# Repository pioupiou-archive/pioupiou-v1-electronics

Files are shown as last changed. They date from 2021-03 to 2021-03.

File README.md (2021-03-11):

# pioupiou-v1-electronics

This repository contains the electronic parts of the Pioupiou V1 wind sensor.

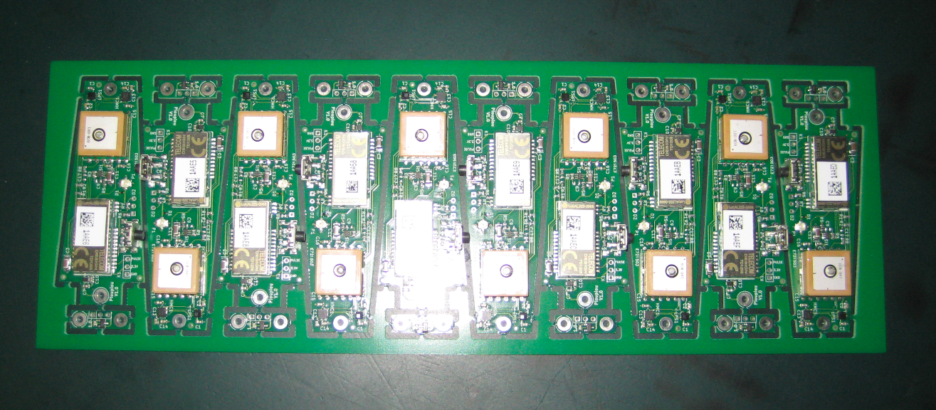
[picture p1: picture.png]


## DEPRECATION NOTICE
**THIS REPOSITORY IS NO LONGER ACTIVE.**

**PLEASE MOVE TO THE NEW PROJECT: https://github.com/windbird-sensor/windbird-electronics**

## License

Copyright (c) 2015 Bac Plus Zéro SAS

Copyright (c) 2016 Altostratus SA

Copyright (c) 2021 OpenWindMap SCIC SA and contributors

**Permission is granted to anyone to use this Material for any purpose, including commercial applications, and to alter it and redistribute it freely, subject to the following restrictions:**

**ATTRIBUTION:** You must give appropriate credit, provide a link to the license, and indicate if changes were made. You may do so in any reasonable manner, but not in any way that suggests the licensor endorses you or your use.

**SHARE-ALIKE:** If you remix, transform, or build upon the Material, you must distribute your contributions under the same license as the original. You must include a copy of this License with every copy of this Material or modified version of this Material You distribute or otherwise make available.

**OBLIGATION TO SHARE WITHIN THE OPENWINDMAP NETWORK:** If you use this Material or a modified version of this Material to build a product that collects environmental data, this data must be published within the OpenWindMap network. You must not intentionally degrade the quality of the data, reduce the accuracy of its geolocation or delay its dissemination.

**OPEN-DATA:** If you use this Material or a modified version of this Material to build a product that collects environmental data, this data should be published under an Open-Data license. The chosen license must allow free reuse and redistribution, including from commercial entities and for commercial use. The choosen license must either be compliant with the [Open Definition](https://opendefinition.org/od/2.1/en/) or receive approval from OpenWindMap's board. You are allowed to offer a version of this data under any other license of your choice (including non-free licenses), as long as you also provide an identical version of this data under an Open-Data license as defined in this paragraph.

**DISCLAIMER OF WARRANTY/LIMITATION OF REMEDIES:** OpenWindMap and its contributors have no obligation to support this Material. OpenWindMap and its contributors are providing this Material "AS IS", with no express or implied warranties of any kind, including, but not limited to, any implied warranties of merchantability or fitness for any particular purpose or warranties against infringement of any proprietary rights of a third party.

**OpenWindMap and its contributors will not be liable for any consequential, incidental, or special damages, or any other relief, or for any claim by any third party, arising from your use of this Material.**

For the avoidance of doubt, OpenWindMap may offer this Material under separate terms or conditions or stop distributing this Material at any time; however, doing so will not terminate this License.

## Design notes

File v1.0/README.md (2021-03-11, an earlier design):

Attention : incohérence de numérotation des composants entre le schéma PDF et les autres fichiers

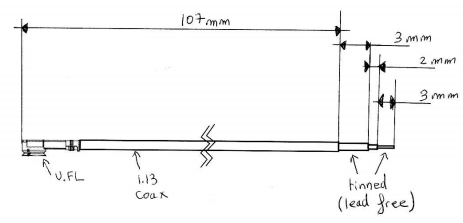
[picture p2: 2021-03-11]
v1.1/antenna coax cable.jpg

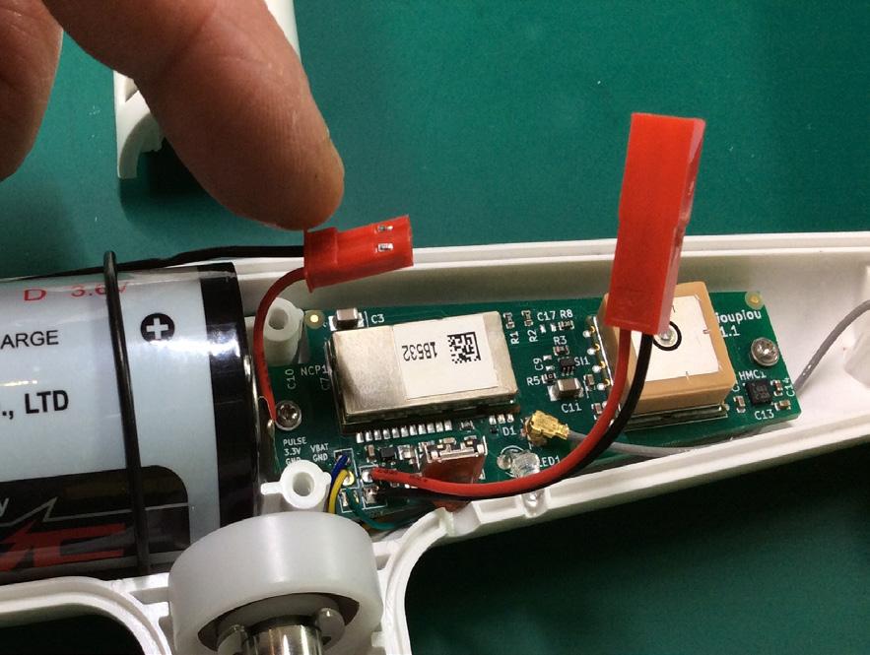
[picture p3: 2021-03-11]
v1.1/battery connector polarity.jpg

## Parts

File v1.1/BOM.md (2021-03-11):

| **Designator** | **Package** | **Quantity** | **Designation** |
| --- | --- | --- | --- |
| C3, C11 | 1206 | 2 | 10uF X7R 6.3V 10% |
| C13 | 0603 | 1 | 220nF X7R 6.3V 10% |
| C14 | 0603 | 1 | 4.7uF X5R 6.3V 10% |
| C16,C10,C7,C12,C15,C6 | 0603 | 6 | 100nF X7R 6.3V 10% |
| C17,C9 | 0603 | 2 | do not populate |
| C8 | 0603 | 1 | 10nF X7R 6.3V 10% |
| D1 | sod923 | 1 | ESD9R3.3ST5G |
| LED1 | Trough-hole | 1 | LTL1CHKEKNN |
| NCP1 | SC70 | 1 | NCP4681DSQ33T1G |
| P1 | UFL | 1 | U.FL-R-SMT-1 |
| R3 | 0603 | 1 | 1M 1% |
| R4,R1,R2 | 0603 | 3 | 10k 1% |
| R5 | 0603 | 1 | 0R |
| R6 | 0603 | 1 | 68 1% |
| R8 | 0603 | 1 | 10K 1% |
| SI1 | SC70-6 | 1 | SI1865DDL-T1-GE3 |
| SW1 | smd switch  | 1 | 1571300-2 (TE Connectivity) |
| TD1 | module | 1 | TD1208R |
| TMR1 | sot23 | 1 | TMR1202 / TMR1208 |
| HMC1 | lcc 3x3mm | 1 | HMC5883L |
| QL1 | module | 1 | L80 |

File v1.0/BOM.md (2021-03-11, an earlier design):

| Designator | Package | Quantity | Designation  |
| --- | --- | --- | --- |
| C0,C1,C7,C10,C12,C15,C16 | 603 | 7 | 100nF X7R |
| C13 | 603 | 1 | 220nF X7R |
| C17,C9 | 603 | 2 | vide |
| C2,C14 | 603 | 2 | 4.7uF X7R |
| C3,C11 | 1206 | 2 | 10uF/6V3 X7R |
| C8 | 603 | 1 | 10nF X7R |
| D1 | SOD923 | 1 | ESD9R3.3ST5G |
| D2 | through-hole | 1 | ??? |
| HMC1 | LPCC | 1 | HMC5883L |
| LPS1 | HLGA | 1 | LPS25HB |
| MMS1 | 603 | 1 | MMS1X1HS |
| NCP1 | SC70 | 1 | NCP4681 |
| P1 | U.FL | 1 | A-1JB |
| QL1 | module | 1 | L80 |
| R1,R2,R4,R8 | 603 | 4 | 10k |
| R3 | 603 | 1 | 1M |
| R5 | 603 | 1 | 0R |
| R7,R6 | 603 | 2 | 68R |
| SI1 | SC70 | 1 | SI1865DL |
| SW1 | smd switch | 1 | 1571300 |
| TD1 | module | 1 | TD1208 |

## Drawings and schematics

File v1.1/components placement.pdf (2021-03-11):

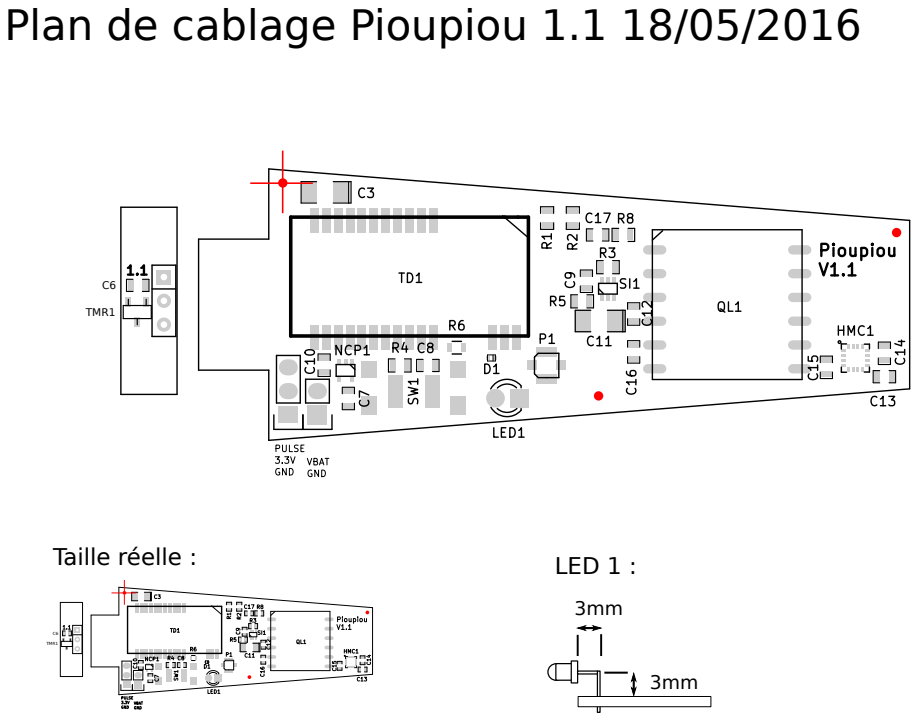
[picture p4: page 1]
TMR1; Taille réelle :; LED 1 :

Plan de cablage Pioupiou 1.1 18/05/2016

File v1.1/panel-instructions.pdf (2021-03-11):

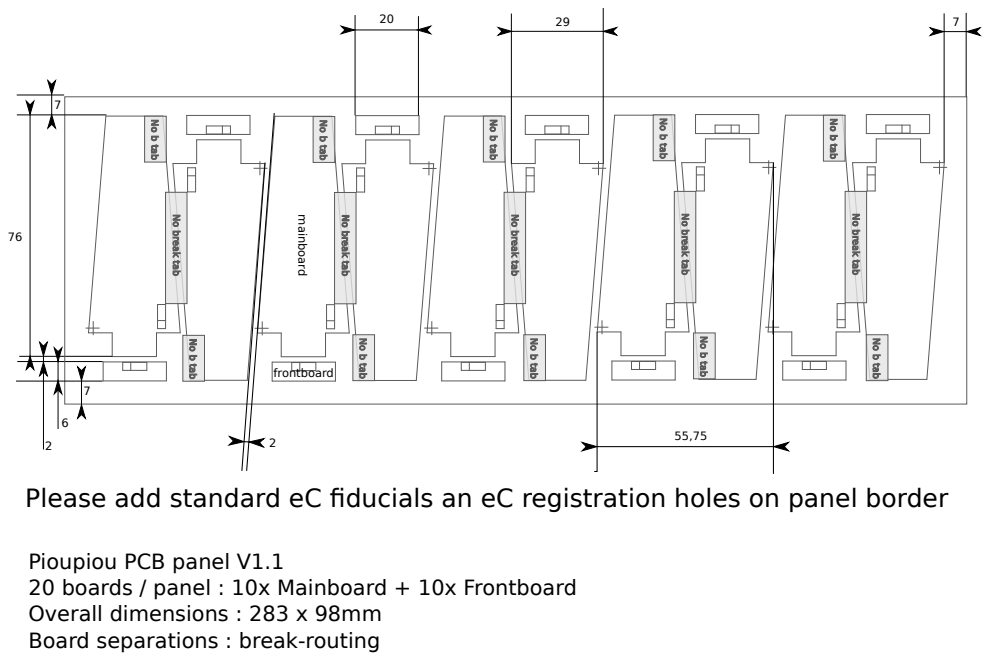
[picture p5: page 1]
frontboard; No b tab; Please add standard eC fiducials an eC registration holes on panel border No b tab

Board separations : break-routing mainboard

No break tab

Pioupiou PCB panel V1.1
20 boards / panel : 10x Mainboard + 10x Frontboard
Overall dimensions : 283 x 98mm

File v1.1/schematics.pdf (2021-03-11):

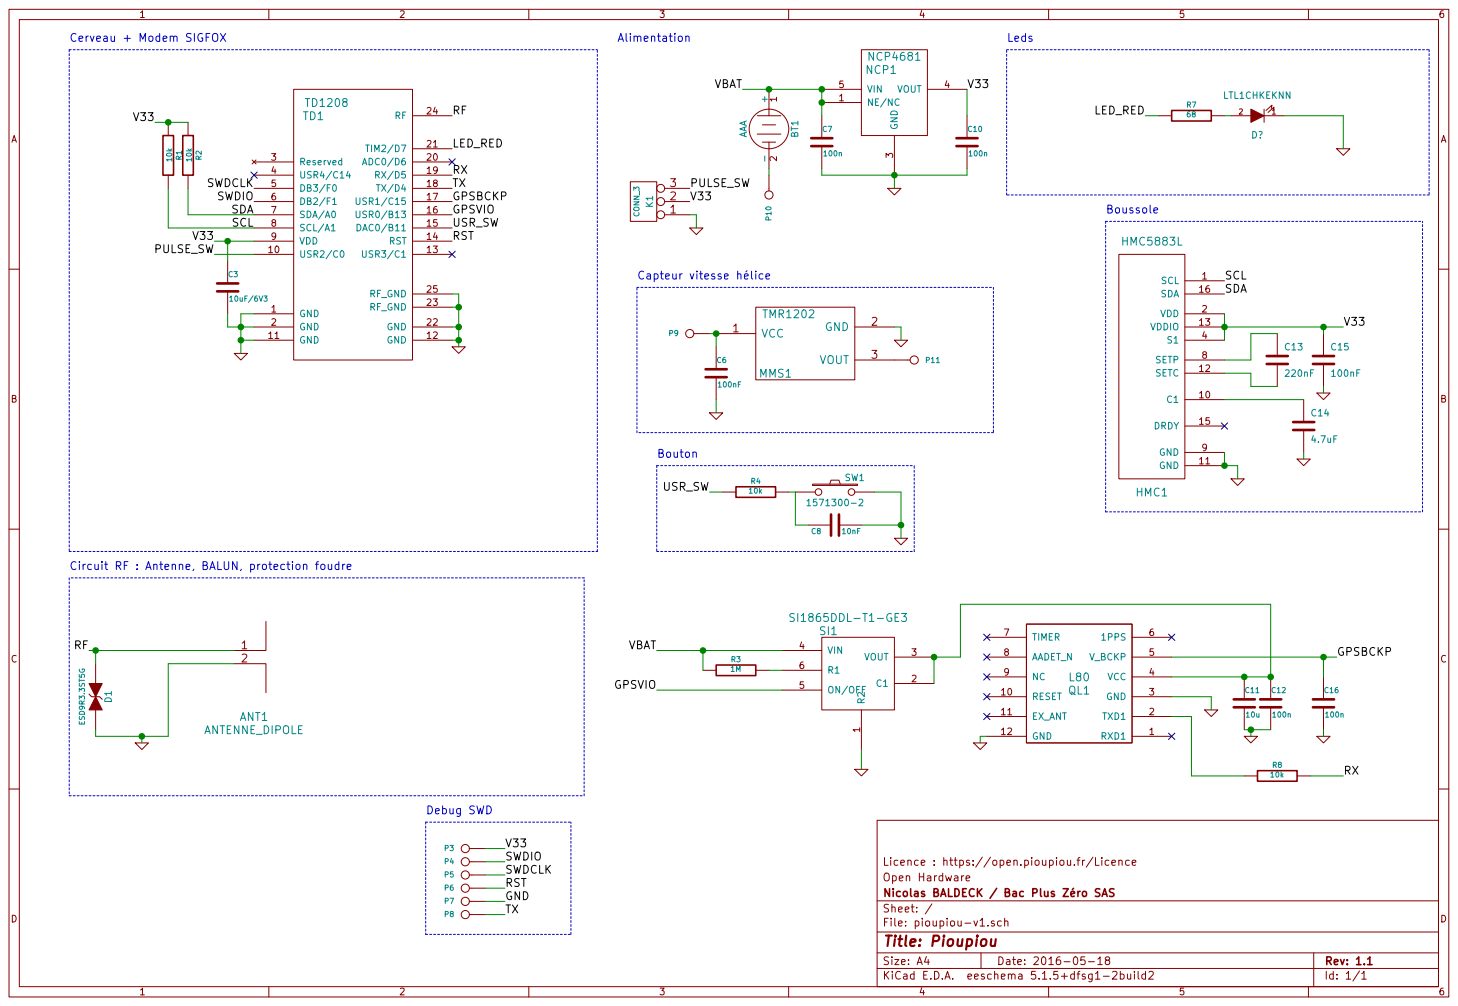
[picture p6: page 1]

Leds Capteur vitesse hélice
10uF/6V3 D1 ESD9R3.3ST5G

Licence : https://open.pioupiou.fr/Licence
Open Hardware
File: pioupiou-v1.sch Sheet: / Nicolas BALDECK / Bac Plus Zéro SAS

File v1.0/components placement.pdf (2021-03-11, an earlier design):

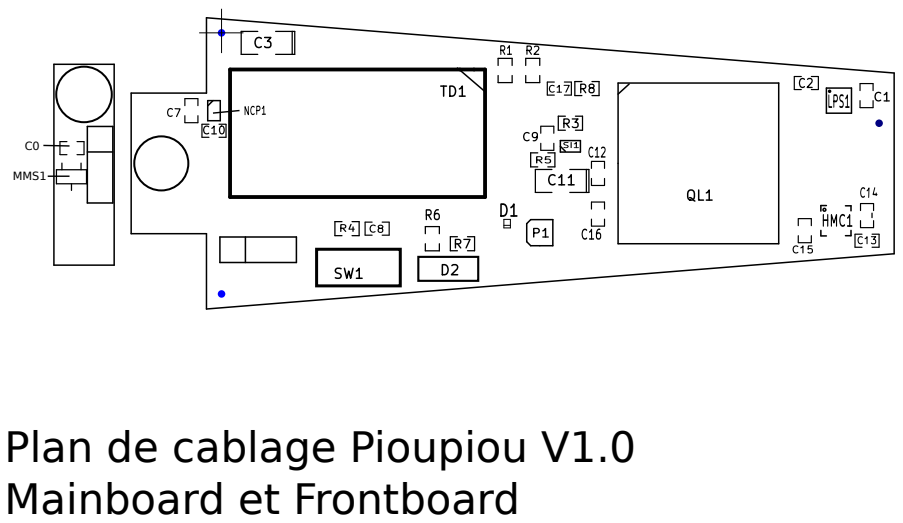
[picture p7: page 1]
MMS1

Plan de cablage Pioupiou V1.0
Mainboard et Frontboard

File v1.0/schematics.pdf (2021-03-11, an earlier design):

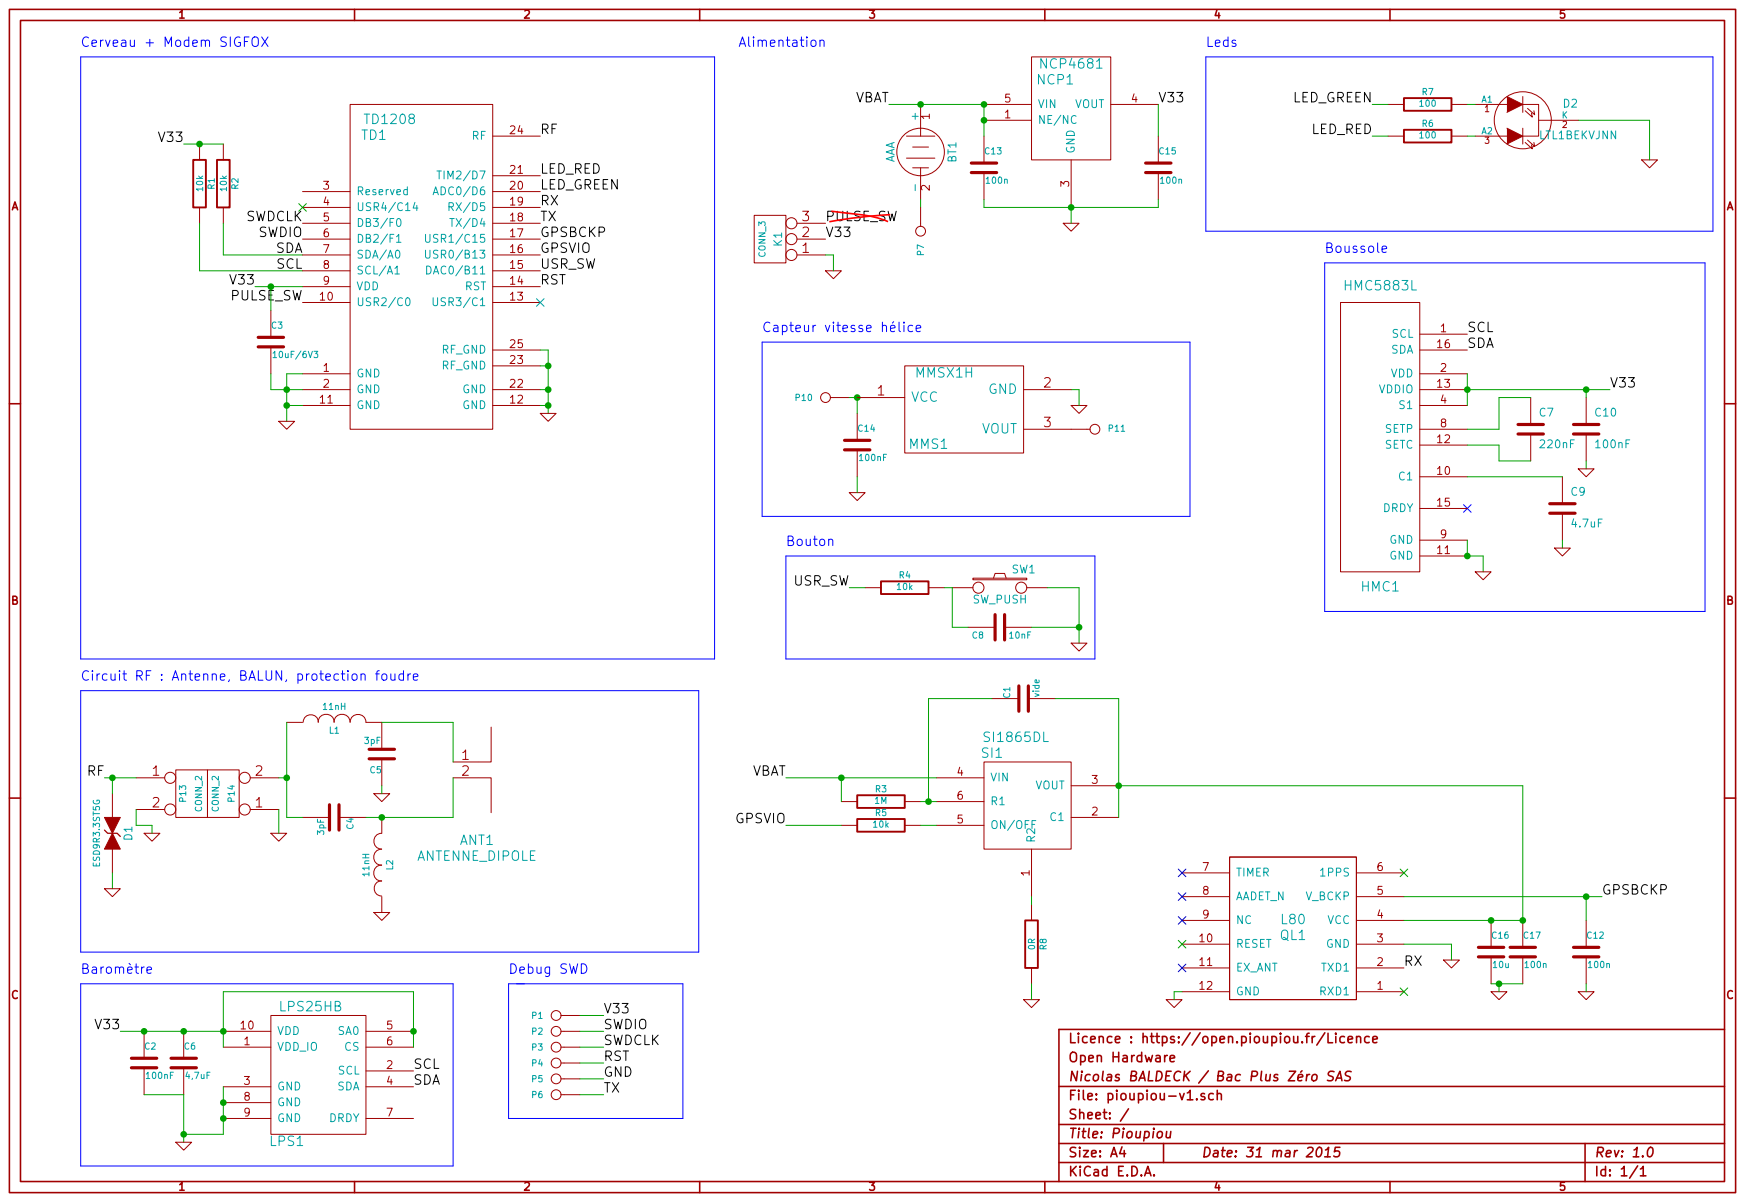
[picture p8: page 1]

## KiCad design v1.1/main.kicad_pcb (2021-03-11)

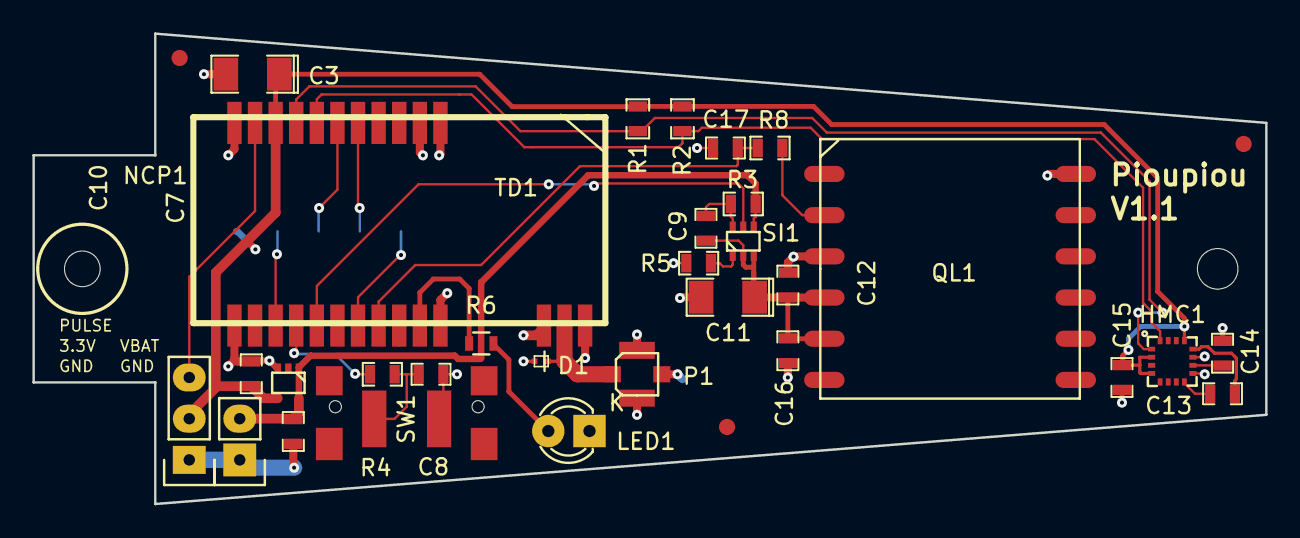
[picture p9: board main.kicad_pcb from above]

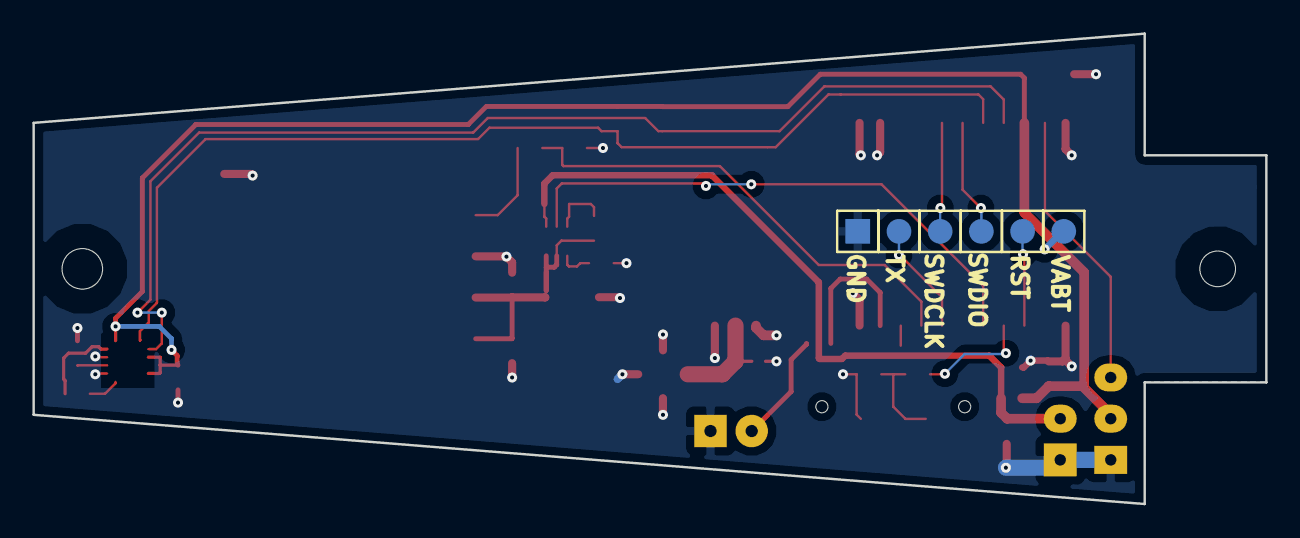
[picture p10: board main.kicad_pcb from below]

Board: 2 copper layers, 76.0 x 29.0 mm, 39 parts (6 on the bottom side), 23 nets.

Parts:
BT1: AAA; VIS_BATTERIE
C3: 10uF/6V3; SM1206POL
C7, C10, C12, C16: 100n; SM0603_Capa
C8: 10nF; SM0603_Capa
C9, C17: vide; SM0603_Capa
C11: 10u; SM1206POL
C13: 220nF; SM0603_Capa
C14: 4.7uF; SM0603_Capa
C15: 100nF; SM0603_Capa
D1: ESD9R3.3ST5G; sod923
HMC1: HMC5883L
K1: CONN_3; Socket_Strip_Straight_1x03
LED1: LED-3MM
MIRE-1MM, MIRE-1MM#2, MIRE-1MM#3: VAL**; MIRE-1MM
NCP1: NCP4681
P1: CONN_2; UFL
P3, P4, P5, P6, P7, P8: CONN_1; PIN_ARRAY_1
QL1: L80; PA6H
R1, R2, R4: 10k; SM0603_Resistor
R3: 1M; SM0603_Resistor
R5: 0R; SM0603_Resistor
R6: R_0603
R8: 10K; SM0603_Resistor
SI1: SI1865DL; si1865dl
SW1: SW_PUSH; 1571300
TD1: TD1208

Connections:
/GPSBCKP: C16.1, QL1.5, TD1.17
/GPSVIO: SI1.5, TD1.16
/PULSE_SW: K1.3, TD1.10
/RF: D1.1, P1.1, TD1.24
/RST: P6.1, TD1.14
/RX: C17.1, R8.2, TD1.19
/SCL: HMC1.1, R1.2, TD1.8
/SDA: HMC1.16, R2.2, TD1.7
/SWDCLK: P5.1, TD1.5
/SWDIO: P4.1, TD1.6
/TX: P8.1, TD1.18
/USR_SW: R4.1, TD1.15
/V33: C3.1, C10.1, C15.1, HMC1.2, HMC1.4, HMC1.13, K1.2, NCP1.4, P3.1, R1.1, R2.1, TD1.9
/VBAT: C7.1, NCP1.1, NCP1.5, R3.1, SI1.4
GND: C3.2, C7.2, C8.2, C10.2, C11.2, C12.2, C14.2, C15.2, C16.2, C17.2, D1.2, HMC1.9, HMC1.11, K1.1, LED1.1, NCP1.3, P1.2, P7.1, QL1.3, QL1.12, R5.2, SW1.2, TD1.1, TD1.2, TD1.11, TD1.12, TD1.22, TD1.23, TD1.25
unnamed: R5.1, SI1.1
unnamed: QL1.2, R8.1
unnamed: C9.1, R3.2, SI1.6
unnamed: C9.2, C11.1, C12.1, QL1.4, SI1.2, SI1.3
unnamed: C14.1, HMC1.10
unnamed: C13.1, HMC1.8
unnamed: C13.2, HMC1.12
unnamed: C8.1, R4.2, SW1.1

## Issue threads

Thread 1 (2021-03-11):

V1.0 : incohérence de numérotation

nbald, 2021-03-11:
Pour le V1.0 :
Il y a une incohérence de numérotation des composants entre le schéma PDF et les autres fichiers (BOM, pcb, etc...).
Ça serait chouette si quelqu'un pouvait éditer le fichier PDF pour le corriger. On peut faire ça avec un logiciel comme [Inkscape](https://inkscape.org/fr/)

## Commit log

2021-03-11 Archive upload
    [front.kicad_pcb, main+front.kicad_pcb, main.kicad_pcb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]
2021-03-11 battery connector
